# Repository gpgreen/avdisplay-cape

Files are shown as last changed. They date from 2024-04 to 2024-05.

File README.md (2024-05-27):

# Avdisplay Cape

Kicad design for beaglebone black cape. Provides Dual CAN bus & bus
protection. Provides 4A of 5V power to the beaglebone black using dual
offboard 1.5A switching power supplies. These are load balanced using
a LTC4370 device. Since the project is also using a LCD display, only
one of the beaglebone's dual CAN devices is available due to pin
conflicts, so another external MCP2515 CAN controller connected via SPI is
onboard.

## Offboard power supplies

The design is intended to use two Sparkfun [buck boost power
supplies](https://www.sparkfun.com/products/15208) which use a
TPS63070 device. The input range is 3-16V. The project is supplied
from a 12V system. The output on the breakout boards is selected to 5V
and each device connected to the board with the provided JST
connectors. With a heatsink installed on each device, they are capable
of providing 2A for a total of 4A. The 12V input should have diode
protection and a fuse as those are not installed on either the
buck-boost breakout boards or the cape.

## View and Schematics

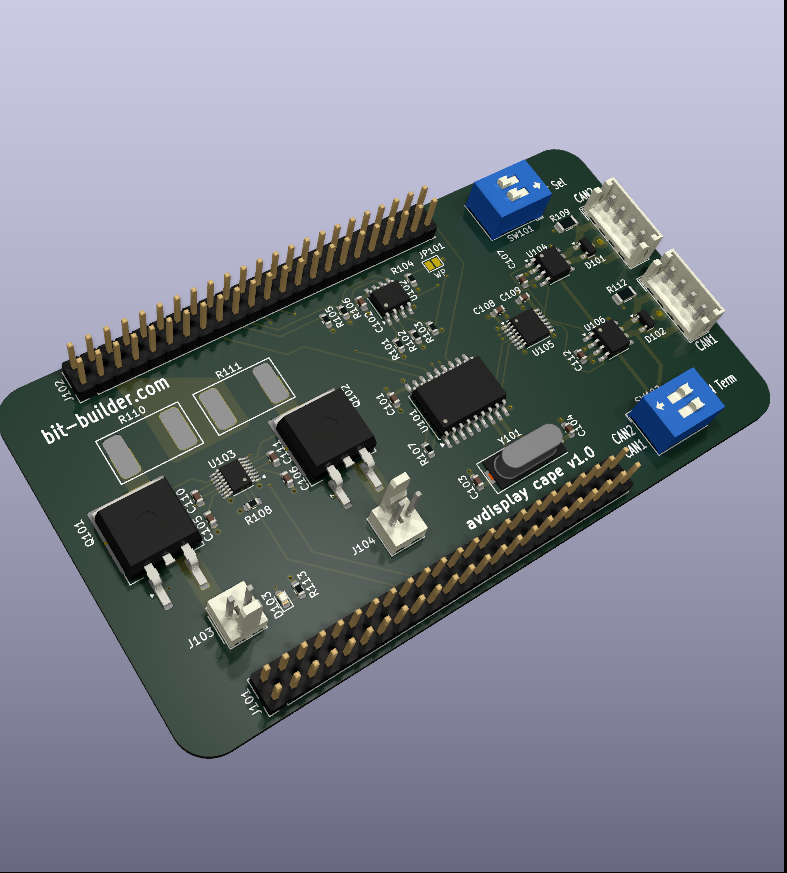
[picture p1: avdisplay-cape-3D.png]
3D View


Schematics

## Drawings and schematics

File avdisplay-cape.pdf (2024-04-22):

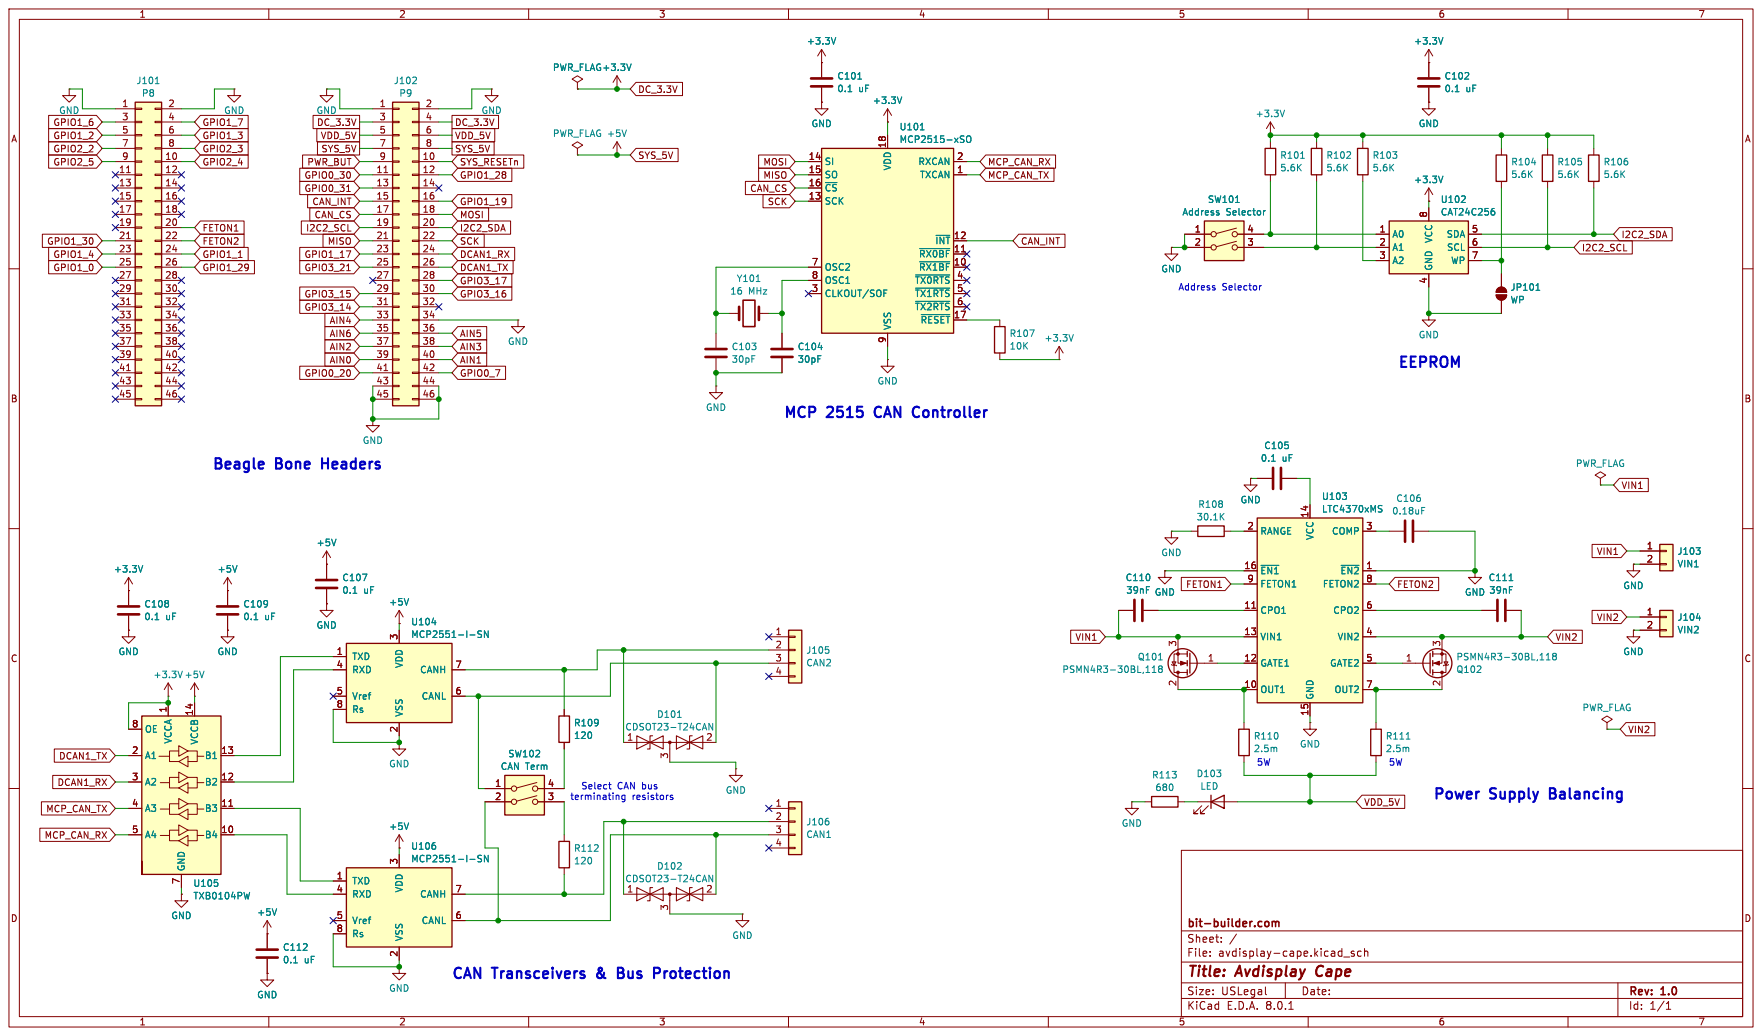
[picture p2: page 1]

4 SDA 5 SCL 6 WP 7 VCC
5WEEPROM

3 RXD 4 Vref 5 CANL 6 CANH 7 Rs 8 U106 MCP2551-I-SN GND

3 RXD 4 Vref 5 CANL 6 CANH 7 Rs 8 U104 MCP2551-I-SN

3 RXD 4 Vref 5 CANL 6 CANH 7 Rs 8

3 RXD 4 Vref 5 CANL 6 CANH 7 Rs 8 GND

File: avdisplay-cape.kicad_sch Sheet: / bit-builder.com

Id: 1/1 Title: Avdisplay Cape

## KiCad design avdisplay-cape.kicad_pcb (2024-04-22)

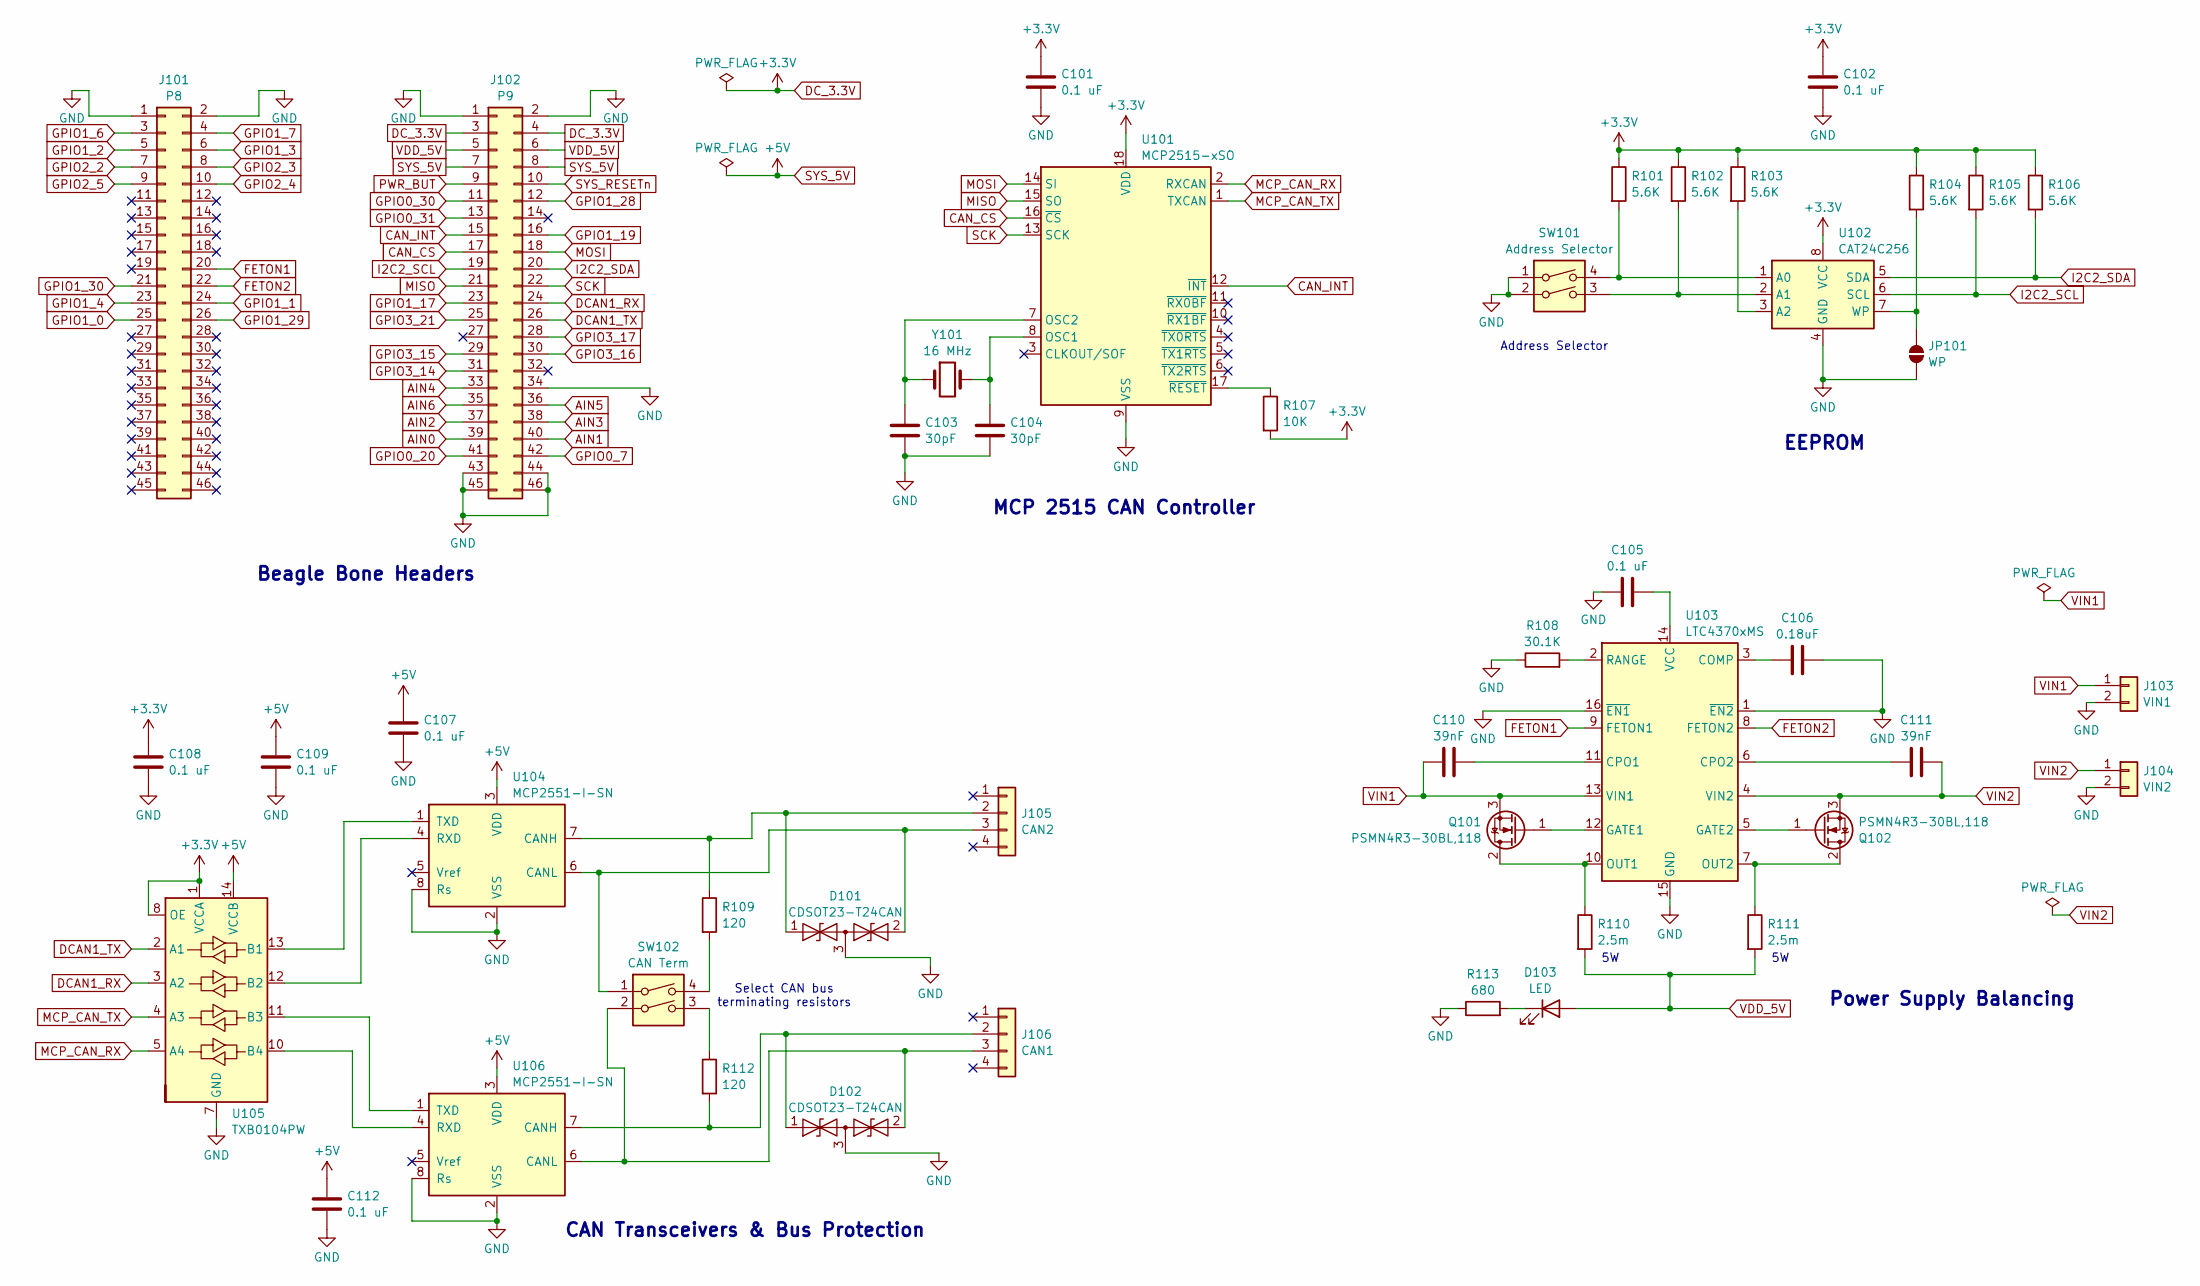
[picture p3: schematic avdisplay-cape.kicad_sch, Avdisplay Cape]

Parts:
C101, C102, C105, C107, C108, C109, C112: 0.1 uF; C_0603_1608Metric
C103, C104: 30pF; C_0603_1608Metric
C106: 0.18uF; C_0603_1608Metric
C110, C111: 39nF; C_0603_1608Metric
D101, D102: CDSOT23-T24CAN; SOT-23
D103: LED; LED_0603_1608Metric
J101: P8; PinHeader_2x23_P2.54mm_Vertical
J102: P9; PinHeader_2x23_P2.54mm_Vertical
J103: VIN1; Molex_KK-254_AE-6410-02A_1x02_P2.54mm_Vertical
J104: VIN2; Molex_KK-254_AE-6410-02A_1x02_P2.54mm_Vertical
J105: CAN2; JST_EH_B4B-EH-A_1x04_P2.50mm_Vertical
J106: CAN1; JST_EH_B4B-EH-A_1x04_P2.50mm_Vertical
JP101: WP; SolderJumper-2_P1.3mm_Open_Pad1.0x1.5mm
Q101, Q102: PSMN4R3-30BL,118; TO-263-2
R101, R102, R103, R104, R105, R106: 5.6K; R_0603_1608Metric
R107: 10K; R_0603_1608Metric
R108: 30.1K; R_0603_1608Metric
R109, R112: 120; R_1206_3216Metric
R110, R111: 2.5m; WSLP3921
R113: 680; R_0603_1608Metric
SW101: Address Selector; SW_DIP_SPSTx02_Slide_9.78x7.26mm_W7.62mm_P2.54mm
SW102: CAN Term; SW_DIP_SPSTx02_Slide_9.78x7.26mm_W7.62mm_P2.54mm
U101: MCP2515-xSO; SOIC-18W_7.5x11.6mm_P1.27mm
U102: CAT24C256; SOIC-8_3.9x4.9mm_P1.27mm
U103: LTC4370xMS; MSOP-16_3x4mm_P0.5mm
U104, U106: MCP2551-I-SN; SOIC-8_3.9x4.9mm_P1.27mm
U105: TXB0104PW; TSSOP-14_4.4x5mm_P0.65mm
Y101: 16 MHz; Crystal_SMD_HC49-SD

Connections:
AIN0: J102.39
AIN1: J102.40
AIN2: J102.37
AIN3: J102.38
AIN4: J102.33
AIN5: J102.36
AIN6: J102.35
CAN_CS: J102.17, U101.16 (~CS)
CAN_INT: J102.15, U101.12 (~INT)
DCAN1_RX: J102.24, U105.3 (A2)
DCAN1_TX: J102.26, U105.2 (A1)
DC_3.3V: C101.1, C102.1, C108.1, J102.3, J102.4, R101.1, R102.1, R103.1, R104.1, R105.1, R106.1, R107.2, U101.18 (VDD), U102.8 (VCC), U105.1 (VCCA), U105.8 (OE)
FETON1: J101.20, U103.9 (FETON1)
FETON2: J101.22, U103.8 (FETON2)
GND: C101.2, C102.2, C103.2, C104.2, C105.1, C106.2, C107.2, C108.2, C109.2, C112.2, D101.3 (common), D102.3 (common), J101.1, J101.2, J102.1, J102.2, J102.34, J102.43, J102.44, J102.45, J102.46, J103.2, J104.2, JP101.1 (A), R108.1, R113.1, SW101.1, SW101.2, U101.9 (VSS), U102.4 (GND), U103.1 (~EN2), U103.15 (GND), U103.16 (~EN1), U104.2 (VSS), U104.8 (Rs), U105.7 (GND), U106.2 (VSS), U106.8 (Rs)
GPIO0_7: J102.42
GPIO0_20: J102.41
GPIO0_30: J102.11
GPIO0_31: J102.13
GPIO1_0: J101.25
GPIO1_1: J101.24
GPIO1_2: J101.5
GPIO1_3: J101.6
GPIO1_4: J101.23
GPIO1_6: J101.3
GPIO1_7: J101.4
GPIO1_17: J102.23
GPIO1_19: J102.16
GPIO1_28: J102.12
GPIO1_29: J101.26
GPIO1_30: J101.21
GPIO2_2: J101.7
GPIO2_3: J101.8
GPIO2_4: J101.10
GPIO2_5: J101.9
GPIO3_14: J102.31
GPIO3_15: J102.29
GPIO3_16: J102.30
GPIO3_17: J102.28
GPIO3_21: J102.25
I2C2_SCL: J102.19, R105.2, U102.6 (SCL)
I2C2_SDA: J102.20, R106.2, U102.5 (SDA)
MCP_CAN_RX: U101.2 (RXCAN), U105.5 (A4)
MCP_CAN_TX: U101.1 (TXCAN), U105.4 (A3)
MISO: J102.21, U101.15 (SO)
MOSI: J102.18, U101.14 (SI)
unnamed: D101.1 (A1), J105.2, R109.1, U104.7 (CANH)
unnamed: D101.2 (A2), J105.3, SW102.1, U104.6 (CANL)
unnamed: D102.1 (A1), J106.2, R112.2, U106.7 (CANH)
unnamed: D102.2 (A2), J106.3, SW102.2, U106.6 (CANL)
unnamed: D103.1 (K), R113.2
unnamed: JP101.2 (B), R104.2, U102.7 (WP)
unnamed: Q101.2 (D), R110.1, U103.10 (OUT1)
unnamed: Q101.1 (G), U103.12 (GATE1)
unnamed: Q102.2 (D), R111.1, U103.7 (OUT2)
unnamed: Q102.1 (G), U103.5 (GATE2)
unnamed: R109.2, SW102.4
unnamed: R112.1, SW102.3
unnamed: C104.1, U101.8 (OSC1), Y101.2
unnamed: C103.1, U101.7 (OSC2), Y101.1
unnamed: R107.1, U101.17 (~RESET)
unnamed: R101.2, SW101.4, U102.1 (A0)
unnamed: R102.2, SW101.3, U102.2 (A1)
unnamed: R103.2, U102.3 (A2)
unnamed: C106.1, U103.3 (COMP)
unnamed: C110.2, U103.11 (CPO1)
unnamed: C111.1, U103.6 (CPO2)
unnamed: R108.2, U103.2 (RANGE)
unnamed: C105.2, U103.14 (VCC)
unnamed: U104.4 (RXD), U105.12 (B2)
unnamed: U104.1 (TXD), U105.13 (B1)
unnamed: U105.11 (B3), U106.1 (TXD)
unnamed: U105.10 (B4), U106.4 (RXD)
PWR_BUT: J102.9
SCK: J102.22, U101.13 (SCK)
SYS_5V: C107.1, C109.1, C112.1, J102.7, J102.8, U104.3 (VDD), U105.14 (VCCB), U106.3 (VDD)
SYS_RESETn: J102.10
VDD_5V: D103.2 (A), J102.5, J102.6, R110.2, R111.2
VIN1: C110.1, J103.1, Q101.3 (S), U103.13 (VIN1)
VIN2: C111.2, J104.1, Q102.3 (S), U103.4 (VIN2)

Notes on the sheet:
EEPROM
Beagle Bone Headers
CAN Transceivers & Bus Protection
MCP 2515 CAN Controller
Power Supply Balancing
Select CAN bus terminating resistors
Address Selector

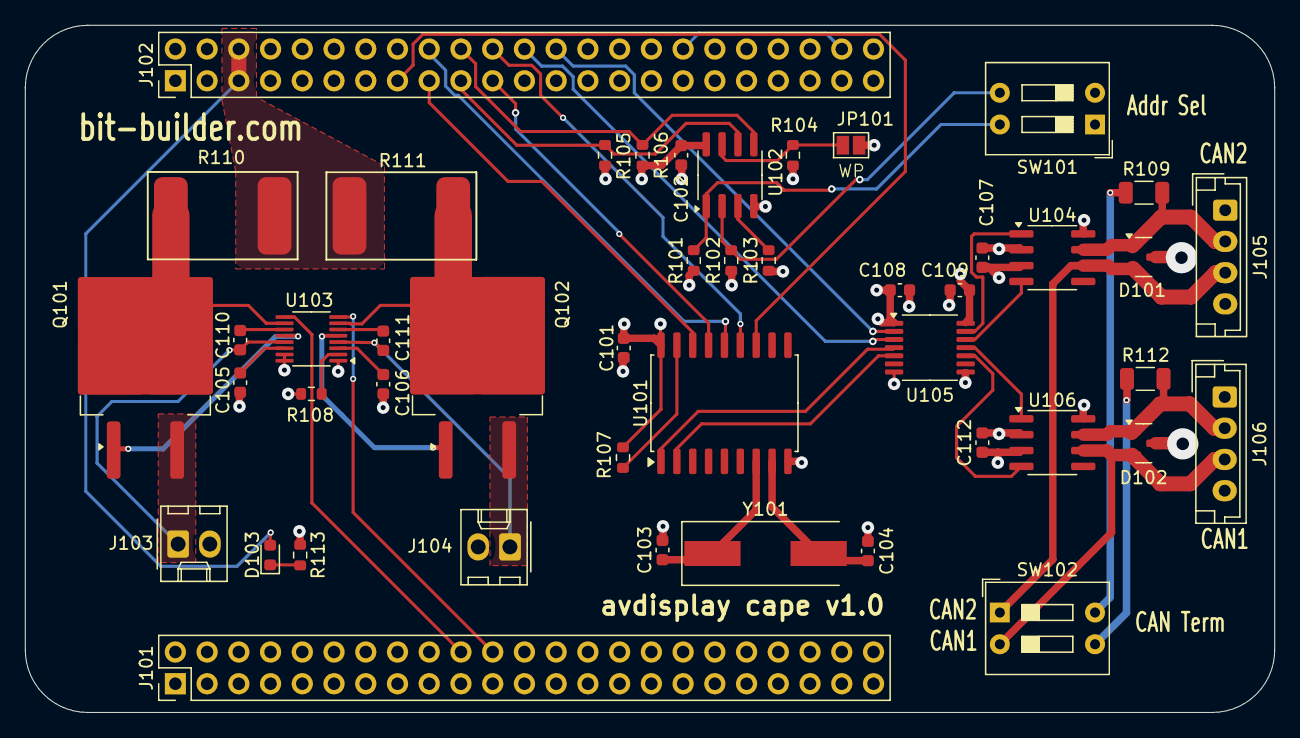
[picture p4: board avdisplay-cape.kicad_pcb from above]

Board: 4 copper layers, 100.0 x 55.0 mm, 46 parts (0 on the bottom side), 46 nets.
